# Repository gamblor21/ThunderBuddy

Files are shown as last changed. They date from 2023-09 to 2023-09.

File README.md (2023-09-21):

# ThunderBuddy

This small circuitboard uses an AS3935 chip to detect lightning at distances up to 40km away. By default it supports SPI but can be configured for I2C as well.

The board measures around 2cm a side with a small lightning shaped antenna area on top.

The board can be driven in CircuitPython with the [AS3935 driver](https://github.com/gamblor21/CircuitPython_AS3935).

For an example project using the board please see my [Lightning Detector](https://github.com/gamblor21/Lightning-Detector) project.

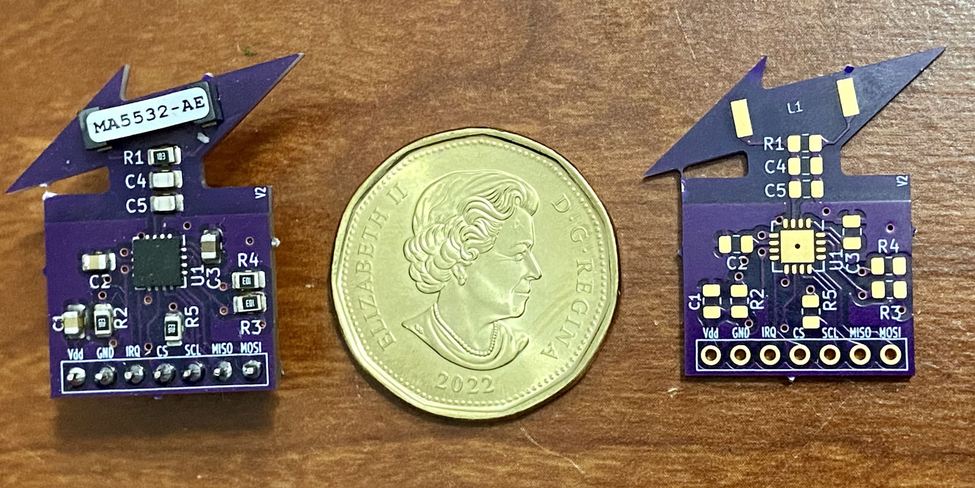
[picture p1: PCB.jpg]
PCB


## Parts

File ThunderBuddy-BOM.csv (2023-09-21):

Reference | Value | Footprint | Datasheet | Qty
C1, C2 | 1uF | Capacitor_SMD:C_0805_2012Metric | ~ | 2
C3 | 10uF | Capacitor_SMD:C_0805_2012Metric | ~ | 1
C4 | 680pf | Capacitor_SMD:C_0805_2012Metric | ~ | 1
C5 | 270pf | Capacitor_SMD:C_0805_2012Metric | ~ | 1
J1 | Headers | Connector_PinHeader_2.54mm:PinHeader_1x07_P2.54mm_Vertical | ~ | 1
JP1 | SI Bridge | Jumper:SolderJumper-2_P1.3mm_Bridged2Bar_RoundedPad1.0x1.5mm | ~ | 1
JP2 | AD0 Bridge | Jumper:SolderJumper-2_P1.3mm_Open_RoundedPad1.0x1.5mm | ~ | 1
JP3 | AD1 Bridge | Jumper:SolderJumper-2_P1.3mm_Open_RoundedPad1.0x1.5mm | ~ | 1
JP4 | SCL Bridge | Jumper:SolderJumper-2_P1.3mm_Open_RoundedPad1.0x1.5mm | ~ | 1
L1 | MA5532-AE | MA5532:MA5532-AE | https://github.com/gamblor21/ThunderBuddy/blob/main/ma5532.pdf | 1
R1-R5 | 10k | Resistor_SMD:R_0805_2012Metric | ~ | 5
U1 | AS3935 | Package_DFN_QFN:MLPQ-16-1EP_4x4mm_P0.65mm_EP2.8x2.8mm | https://github.com/gamblor21/ThunderBuddy/blob/main/AS3935_Data_Sheet-1890433.pdf | 1

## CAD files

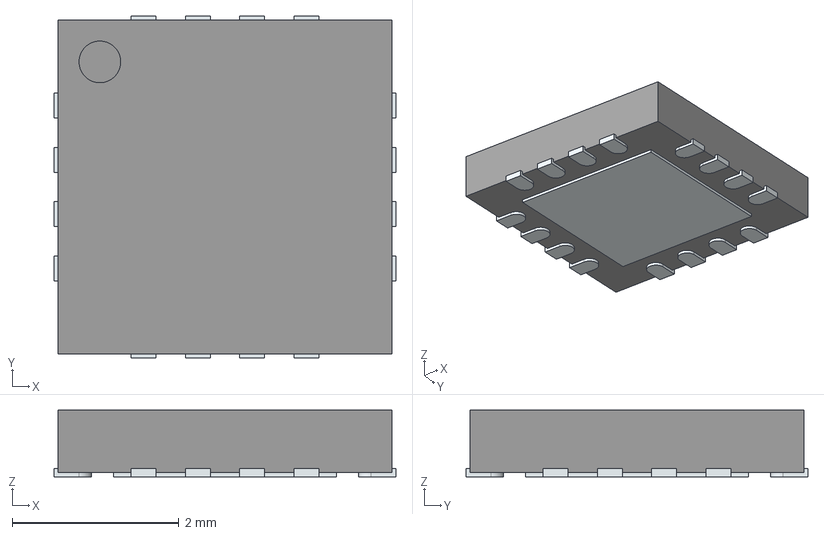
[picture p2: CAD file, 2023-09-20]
Parts/AS3935/3D/AS3935-BQFT.stp
4.10 x 4.10 x 0.8 mm
ThermalPin
PinsArrayLR
PinsArrayTB

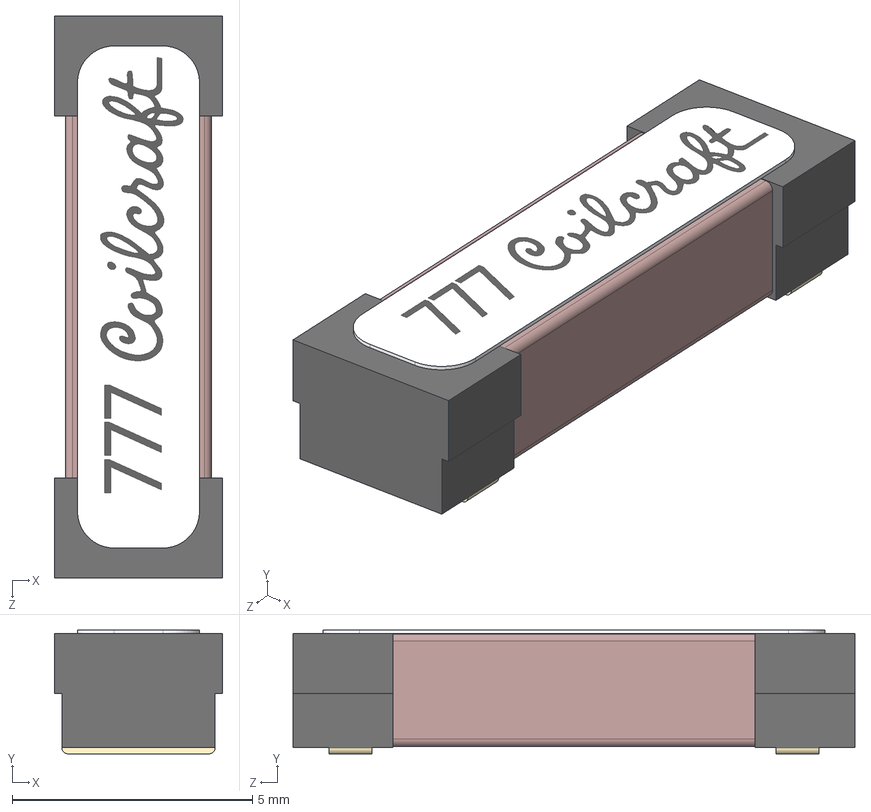
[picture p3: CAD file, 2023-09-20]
Parts/MA5532/Coilcraft-MA5532-AE.STEP
3.50 x 2.58 x 11.7 mm

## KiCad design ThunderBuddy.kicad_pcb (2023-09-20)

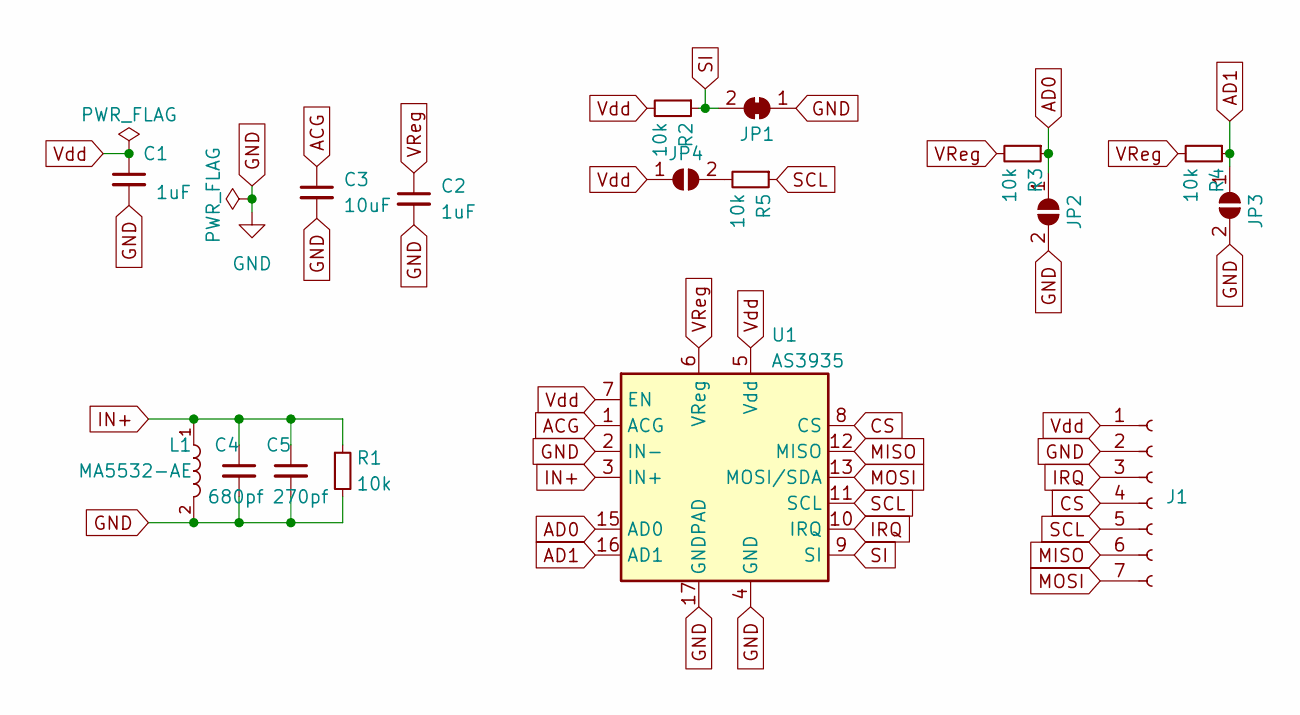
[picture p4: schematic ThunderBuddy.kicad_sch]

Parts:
C1, C2: 1uF; C_0805_2012Metric
C3: 10uF; C_0805_2012Metric
C4: 680pf; C_0805_2012Metric
C5: 270pf; C_0805_2012Metric
J1: Headers; PinHeader_1x07_P2.54mm_Vertical
JP1: SI Bridge; SolderJumper-2_P1.3mm_Bridged2Bar_RoundedPad1.0x1.5mm
JP2: AD0 Bridge; SolderJumper-2_P1.3mm_Open_RoundedPad1.0x1.5mm
JP3: AD1 Bridge; SolderJumper-2_P1.3mm_Open_RoundedPad1.0x1.5mm
JP4: SCL Bridge; SolderJumper-2_P1.3mm_Open_RoundedPad1.0x1.5mm
L1: MA5532-AE
R1, R2, R3, R4, R5: 10k; R_0805_2012Metric
U1: AS3935; MLPQ-16-1EP_4x4mm_P0.65mm_EP2.8x2.8mm

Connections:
ACG: C3.1, U1.1 (ACG)
AD0: JP2.1 (A), R3.1, U1.15 (AD0)
AD1: JP3.1 (A), R4.1, U1.16 (AD1)
CS: J1.4, U1.8 (CS)
GND: C1.2, C2.2, C3.2, C4.2, C5.2, J1.2, JP1.1 (A), JP2.2 (B), JP3.2 (B), L1.2, R1.2, U1.2 (IN-), U1.4 (GND), U1.17 (GNDPAD)
IN+: C4.1, C5.1, L1.1, R1.1, U1.3 (IN+)
IRQ: J1.3, U1.10 (IRQ)
MISO: J1.6, U1.12 (MISO)
MOSI: J1.7, U1.13 (MOSI/SDA)
unnamed: JP4.2 (B), R5.2
SCL: J1.5, R5.1, U1.11 (SCL)
SI: JP1.2 (B), R2.1, U1.9 (SI)
VReg: C2.1, R3.2, R4.2, U1.6 (VReg)
Vdd: C1.1, J1.1, JP4.1 (A), R2.2, U1.5 (Vdd), U1.7 (EN)

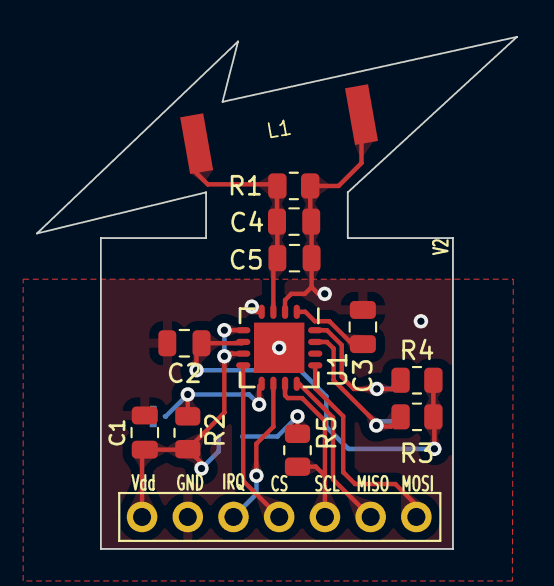
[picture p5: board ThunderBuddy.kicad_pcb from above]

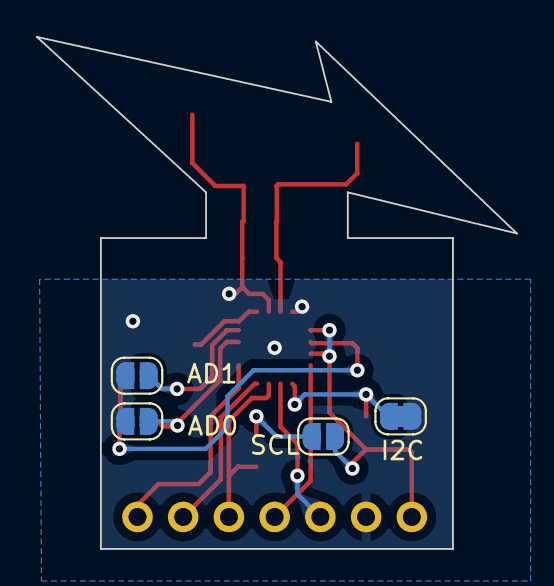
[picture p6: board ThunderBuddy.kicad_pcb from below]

Board: 2 copper layers, 26.7 x 28.4 mm, 17 parts (4 on the bottom side), 14 nets.

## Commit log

2023-09-20 Version 1
    [AS3935-BQFT.stp, Coilcraft-MA5532-AE.STEP, ThunderBuddy.kicad_pcb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]
2023-09-20 Version 2
    [ThunderBuddy.kicad_pcb, ThunderBuddy.kicad_sch]
